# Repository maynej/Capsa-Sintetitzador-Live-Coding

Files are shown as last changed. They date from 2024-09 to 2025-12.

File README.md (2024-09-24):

# Capsa-Sintetitzador-Live-Coding
Es tracta d'una capsa per allotjar el hardware sintetitzador per realitzar Live Coding utilitzant l'entorn de Microblocks 

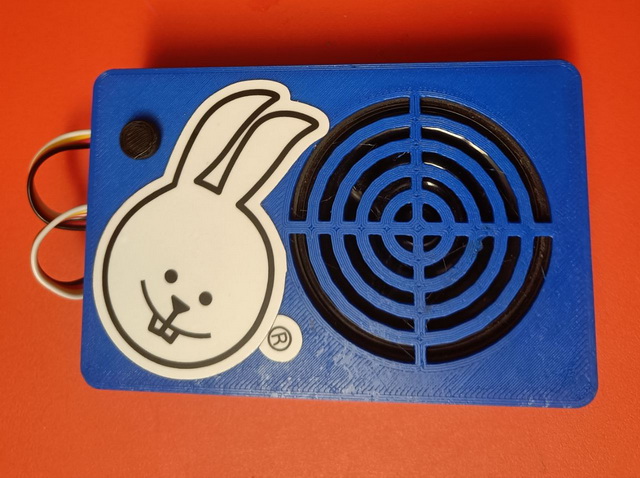
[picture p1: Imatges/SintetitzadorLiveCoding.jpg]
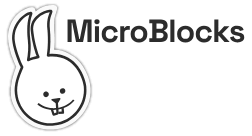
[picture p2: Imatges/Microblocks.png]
 

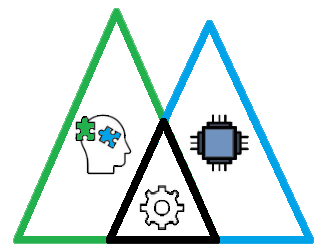
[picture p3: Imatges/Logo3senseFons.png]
Realitzat per [Jordi Mayné](https://github.com/maynej) des de Mechatronic Study jordi.mayne@mechatronicstudy.com 

La documentació està [en PDF](https://github.com/maynej/Capsa-Sintetitzador-Live-Coding/tree/main/DOC/). També amb llengua castellana.

# Arxius per imprimir 
  
Descripció         | Imatge          | Arxiu STL    
------------- | ------------- | ------------- 
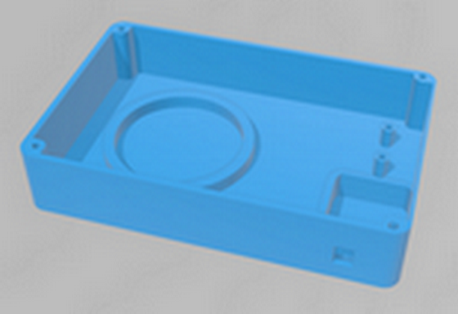
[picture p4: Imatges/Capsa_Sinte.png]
Capsa | | [Capsa](STL/Capsa_Sinte.stl)
Tapa | | [Tapa](STL/TapaPin_Sinte.stl)
Pin Polsador | | [Pin polsador](STL/Pin_Sinte.stl)
 
## Llicència
Creative Commons Attribution-NoComercial-ShareAlike 4.0 International (CC BY-NC-SA 4.0)  

## QR


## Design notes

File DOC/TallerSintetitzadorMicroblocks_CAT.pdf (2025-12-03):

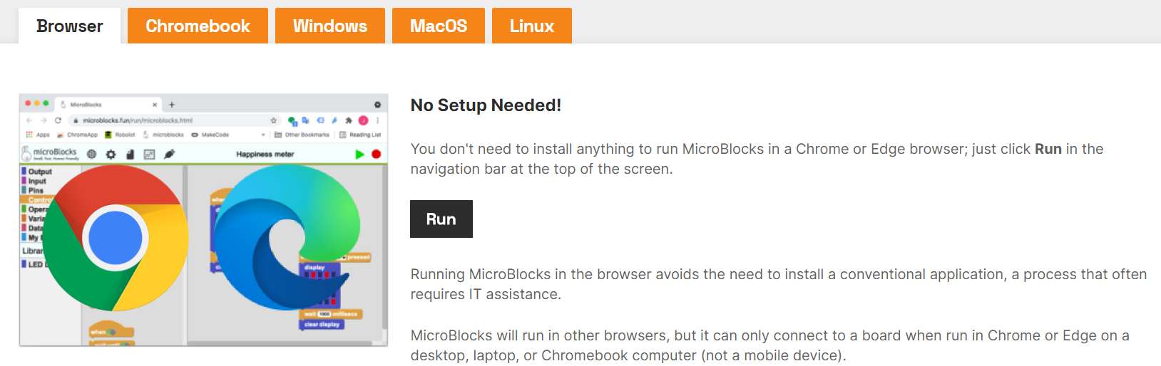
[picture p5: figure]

Jordi Mayné -2026 | 1

## Live Coding – Música programada en directe

“Fa temps que hi ha gent que programa música en directe, davant de públic. Aquesta pràctica es coneix com a «live coding» (programació en directe) i té una comunitat molt activa i apassionada arreu del món.
Normalment, els programadors de «live coding» utilitzen llenguatges que poden produir so per si mateixos, i tot i que els microcontroladors poden produir so per si mateixos, no et serà fàcil fer ballar ningú amb aquests sons.
Els microcontroladors poden interactuar amb dispositius de producció musical mitjançant un protocol anomenat MIDI. És precisament el que farem servir en aquesta activitat.” (extret de Microblocks fun)

# Taller de muntatge d’un sintetitzador

## Microblocks

MicroBlocks és un llenguatge de programació visual basat en blocs, molt basat en Snap! i semblant a d’altres amb programació amb blocs com Scratch...., que us permetrà, de manera molt fàcil i immediata, connectar-vos a diferents plaques i portar a terme projectes de computació física.

MicroBlocks té una característica que el distingeix d'altres llenguatges de programació amb blocs i és que la programació real ocorre segons es desenvolupa el programa, el que podem anomenar com a programació en directe o en viu i, a causa d'això, implica que el codi es descàrrega segons s'escriu i aquest queda gravat com a microprogramari a la placa.

Una altra de les característiques importants que ofereix MicroBlocks és la multitasca, es a dir la possibilitat de desenvolupar funcionalitats que treballen de forma paral·lela i separada, que ens serà molt útil per treballar amb un sintetitzador.

Començar amb MicroBlocks és fàcil! Només heu de seguir aquests senzills passos.

Necessitareu un ordinador (no un dispositiu mòbil!) amb un port USB, un cable USB i un hardware amb diferents possibilitats.

Podeu executar MicroBlocks en un navegador Chrome o Edge des de: https://microblocks.fun/get-started

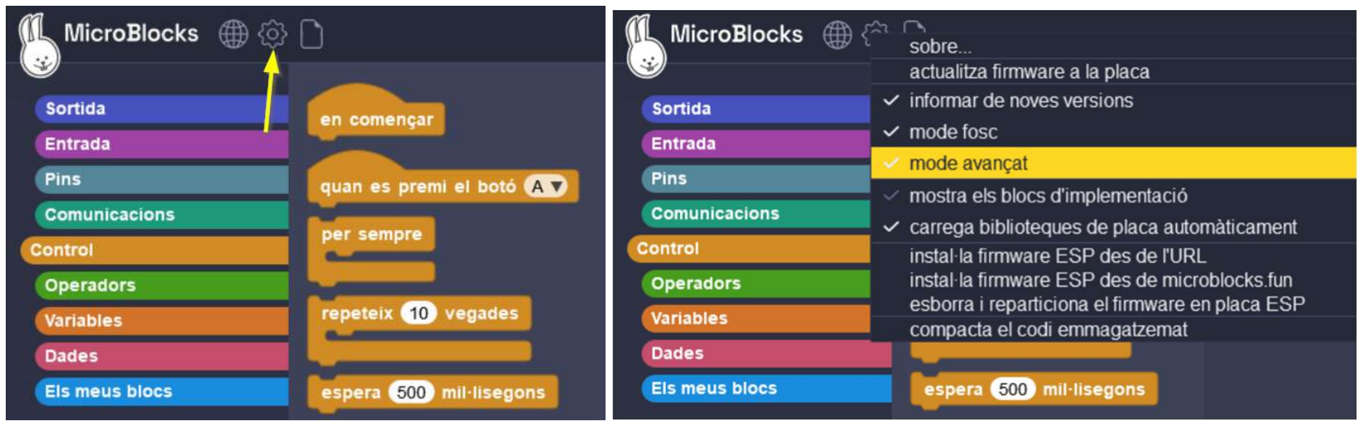
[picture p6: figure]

Jordi Mayné -2026 | 2

O descarregar una aplicació autònoma per a Chromebook, Windows, MacOS o Linux, des de Windows, per exemple, https://microblocks.fun/download. Amb la versió en línia probablement es millor per tenir actualitzades totes les seves funcions.

Al executar Microblocks ens apareixerà l’entorn de treball on podrem primer de tot seleccionar l’idioma.

Desprès cal cridar a les llibreries que farem servir per utilitzar el sintetitzador així com la placa per manegar el sintetitzador. Per el que cal clicar en símbol d’engranatge de MicroBlocks i seleccionar “mode avançat”

En aquest punt tindrem mig preparat l’entorn de programació. Més endavant es veuran els següents passos.

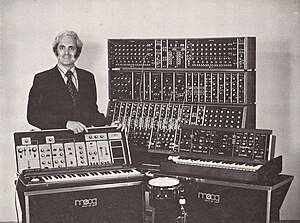
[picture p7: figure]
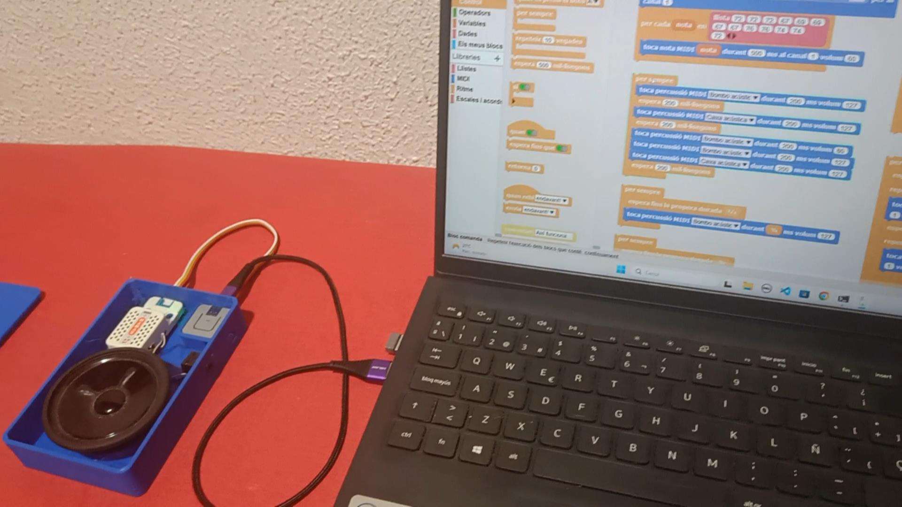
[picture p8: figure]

Jordi Mayné -2026 | 3

### Anem al Sintetitzador

El sintetitzador es un instrument musical electrònic o electròfon, que produeix so, utilitzant variacions de voltatge (en els models analògics) i amb altres tècniques com el mostreig o la modulació de freqüència (en els models digitals).

Els models analògics es van popularitzar de la ma d’en Robert Moog, un enginyer electrònic d’Estats Units en la dècada de 1960, es pot veure en la imatge la majestuositat d’alguns sintetitzadors Moog per generar sons. Que partien d’un teclat i d’una pila d’ajustos per generar freqüències, formes d’ona, harmònics, so envoltant, soroll blanc, trèmols, ... filtres, amplificadors ... d’aquí la seva complexitat, tot i això, es van popularitzar el fes-ho tu mateix, a través d’una revista americana anomenada Mecánica Popular.

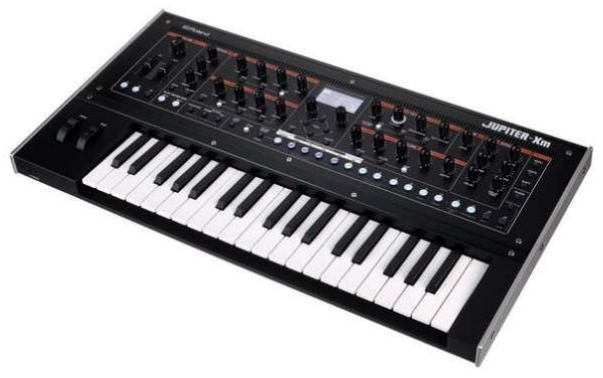
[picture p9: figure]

Avui dia amb els sintetitzadors digitals han miniaturitzat els mateixos i afegeixen moltes noves prestacions que estenen encara més el seu ús, com els “pedalers” per les guitarres elèctriques, bateries electròniques i els sintetitzadors compactes.

Per la comunicació entre sintetitzadors es fa servir un protocol estàndard MIDI (Interfície Digital d’Instruments Musicals), per el que per fer servir aquesta aplicació necessitarem un ordinador amb Microblocks, un processador que comunica entre el PC i el sintetitzador.

Jordi Mayné -2026 | 4

Informació sobre Live Coding: https://learn.microblocks.fun/ca/activities/MIDI-music-ca/

De Sintetitzadors que es poden utilitzar hi ha molts (de tot preu), però també tenim a l’abast un que en quan a preu i qualitat, dels de “fes-ho tu mateix”, els mòduls de la família M5 Stack, on fan servir el processador ESP32 i a més en diferents formats, com el mòdul Atom Matrix o Atom Lite (també s’està provant el AtomS3 Lite) que estan suportats per Microblocks.

Atom Matrix C008-B
https://docs.m5stack.com/en/core/ATOM%20Matrix

Atom Lite C008
https://docs.m5stack.com/en/core/ATOM%20Lite

AtomS3 Lite C124 (falta arranjar perquè funcioni amb el Sintetitzador) https://docs.m5stack.com/en/core/AtomS3%20Lite

Mòdul sintetitzador es el U178, que incorpora el SAM2695 de Dream, un fabricant de xips d’àudio des de 1987. A més incorpora un petit amplificador de 2,8 W i un altaveu, que permet fer un muntatge molt ràpid.
Unit Synth U178 https://docs.m5stack.com/en/unit/Unit-Synth

Es podem comprar a Mouser: https://www.mouser.es/c/?q=m5stack

Muntatge dels mòduls

El mòdul sintetitzador Unit Synth incorpora un cable d’interconnexió amb el mòdul Atom que escollim, en aquest cas Atom Lite, i aquest l’hem de connectar al nostre ordinador mitjançant un cable USB tipus C.

Ara cal instal·lar el firmware de la placa ESP que farem servir.

Anirem a https://microblocks.fun/downloads/pilot/vm/ apareixerà tota la llista i escollirem un dels mòduls Atom que tenim, ens posarem sobre del fitxer i amb el botó dret del ratolí copiarem l’enllaç.

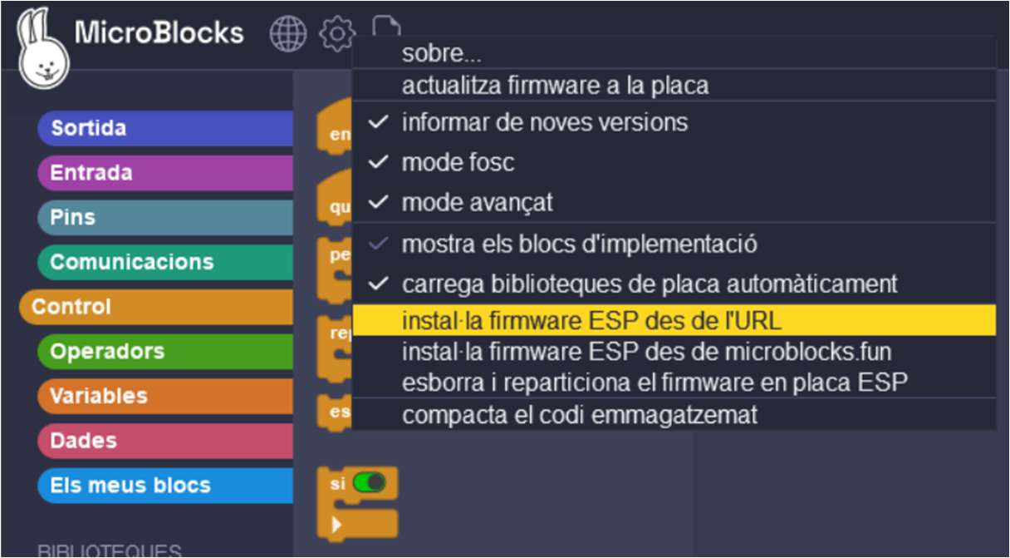
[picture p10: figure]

Jordi Mayné -2026 | 5

Tornem a Microblocks i en la rodona Microblocks seleccionem instal·lar des de la URL i enganxarem el firmware seleccionat anteriorment en la casella “firmware ESP32 des de l’URL”

Enganxarem el firmware seleccionat anteriorment i començarà a instal·lar el firmware, tarda una estona fins que arriba al 100%.

Una vegada endollat el mòdul Atom corresponent en el USB, cal anar al símbol del USB i seleccionar “connecta”

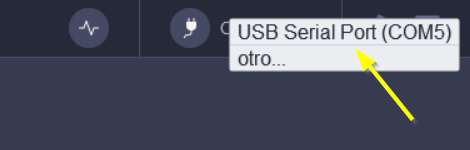
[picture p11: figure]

Ens apareixerà el port USB COM que correspongui en el nostre ordinador i connectarem, quedant el símbol del USB remarcat en color verd.

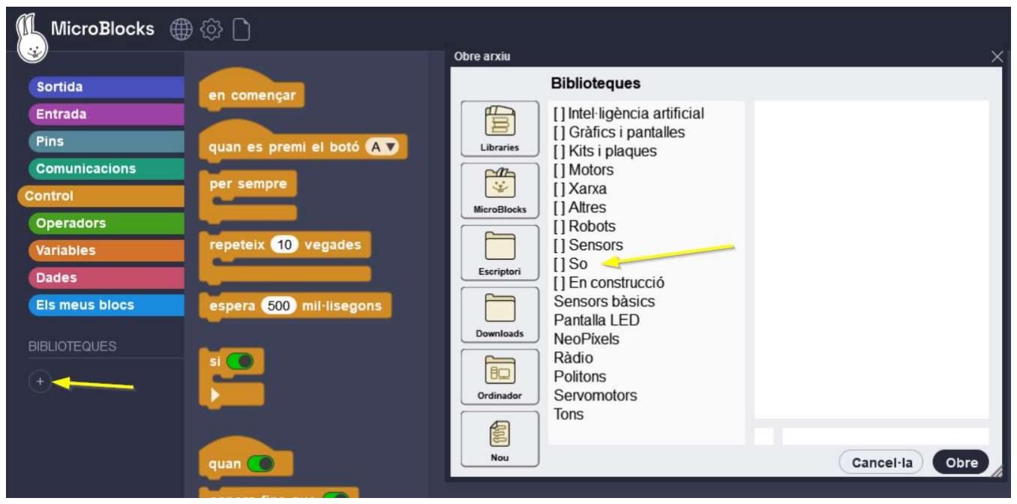
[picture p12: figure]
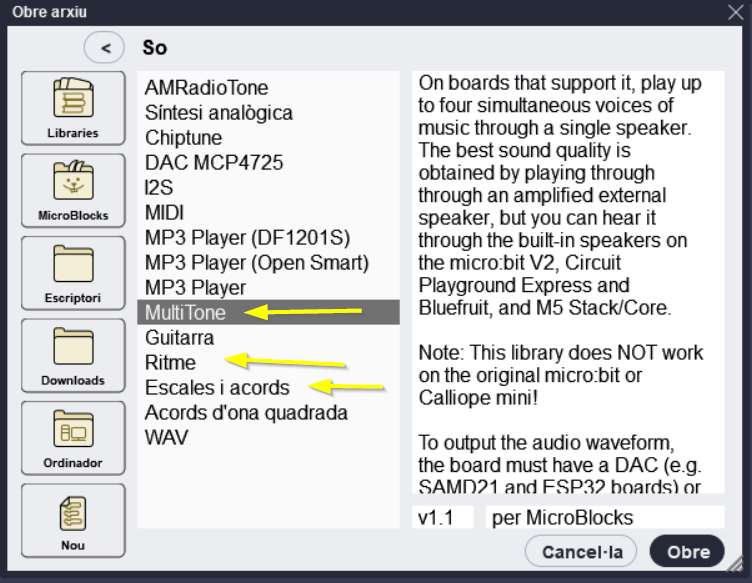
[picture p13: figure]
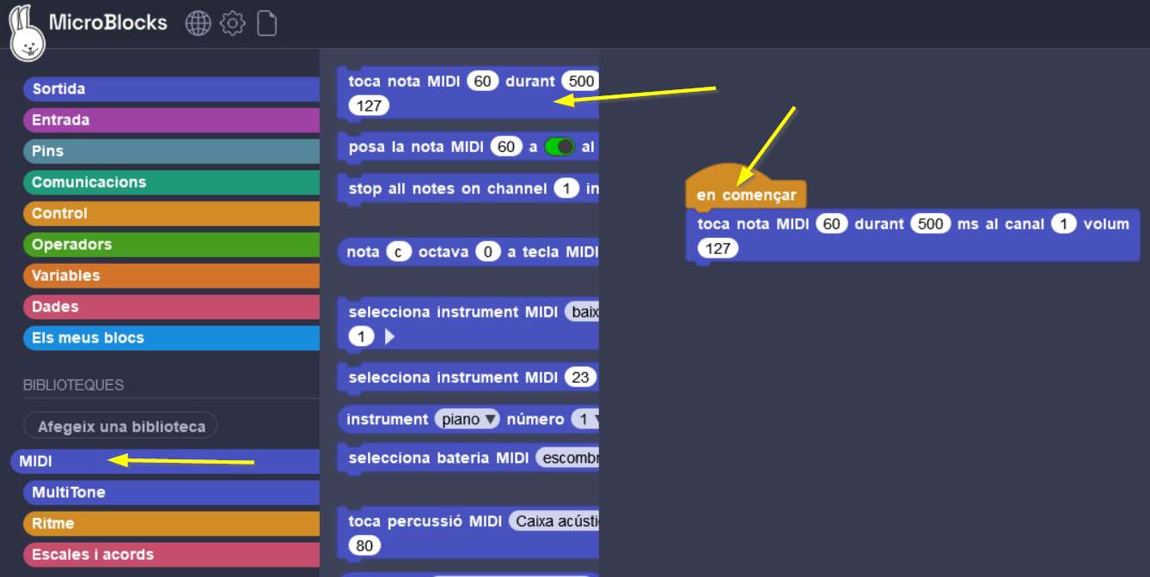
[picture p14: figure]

Jordi Mayné -2026 | 6

Ja només queda afegir les biblioteques de “So”, en la llista de l’esquerra en la part baixa seleccionem “Biblioteques”, i al obrir-se una nova finestra, seleccionarem “So”.

Dintre de “So” la llibreria principal per treballar amb el sintetitzador es MIDI, desprès es poden incloure, Multi-tone, Escales i Acords, Ritme.

Anem a provar si funciona el sintetitzador, seleccionem des de Llibreries, MIDI, i per exemple “toca nota MIDI ...”, al clicar sobre del bloc sentirem el so. Ja tenim preparat per començar a fer un programa de seqüencies.

Jordi Mayné -2026 | 7

Al protocol MIDI, cada nota musical té assignat un determinat número. Això s'entendrà millor sobre un teclat de piano:

A més, els dispositius MIDI poden reproduir música per diferents canals simultàniament. Cada canal també pot configurar-se per reproduir un instrument diferent.

Ritme: La biblioteca de Ritme, proporciona abstraccions per a durades de notes (fraccions de compassos), tempos, compassos i temps. També s'encarrega de mantenir-ho tot sincronitzat.
Aquest és l'aspecte dels blocs per a les durades:
El bloc | representa una rodona. Els altres blocs representen fraccions d'aquesta durada. Per
exemple, | representa una blanca (o la meitat d'una rodona), mentre que | representa una negra.
El tempo, expressat en PPM (pulsacions per minut o, en anglès, BPM: beats per minute), determina la velocitat de reproducció o d'interpretació de la música. A més pulsacions per minut, més ràpida és la música (perquè caben més notes en un minut).

Acords: Els acords són grups de notes que es toquen totes a la vegada. La llibreria d'Escales i acords ofereix diverses maneres de crear acords i progressions d'acords (és a dir, acords que es toquen successivament),
però en aquesta activitat només farem servir el bloc més explícit | .

Arpegis: Quan les notes que formen un acord es toquen individualment de forma successiva, en comptes de totes alhora, això s'anomena arpegi. Com que no les toquem totes de cop, en els arpegis també podem decidir l'ordre en què toquem cadascuna de les notes individuals que el formen. Diferents disposicions de notes poden generar sensacions molt diferents amb un mateix arpegi.

Aquesta informació resumida està extreta de https://learn.microblocks.fun/ca/activities/MIDI-music-ca/ on es pot ampliar els coneixements.

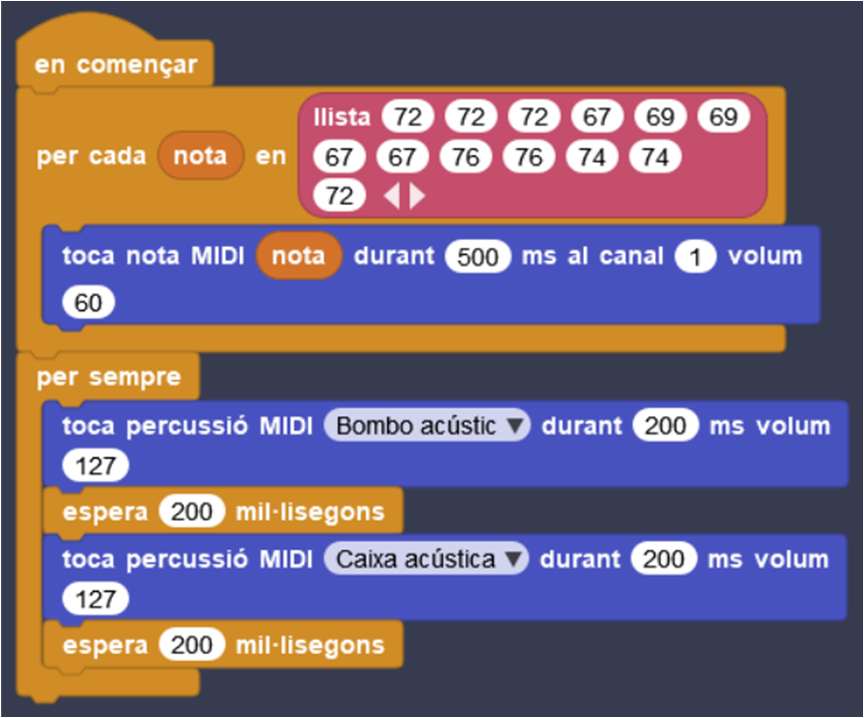
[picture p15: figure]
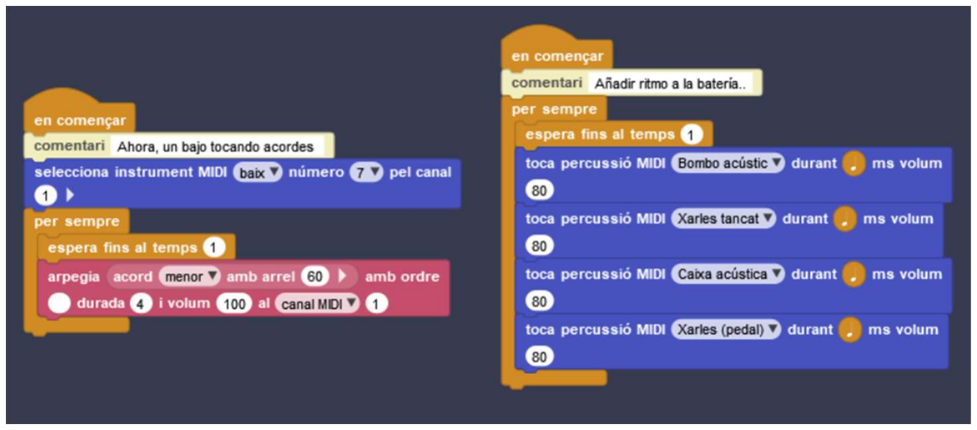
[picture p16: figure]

Jordi Mayné -2026 | 8

Alguns exemples:
Al començar toca una seqüencia de notes molt conegudes, amb una cadència de 500ms cada una i un volum de 100, després s’afegeix com percussió un Bombo acústic durant 200ms i volum 127 (valor màxim), hi ha una espera de 200ms i s’afegeix una nova percussió … i així successivament, el bucle queda tancat en la percussió.

Existeixen 128 notes MIDI i 127 velocitats de tecla possibles. La cançó comença amb 72, 72, 72… que segons la taula correspon a Do,Do,Do de la cinquena octava.

El següent exemple mostra com es selecciona un instrument, per exemple, un baix, després s’obre un llaç per sempre on un arpegi està configurat. A la vegada es pot activar el programa de la dreta amb la percussió.

Jordi Mayné -2026 | 9

### Millora de la qualitat de so del mòdul

Com es podrà entendre el mòdul sintetitzador inclou un altaveu que es molt petit i la qualitat del so, és el que és. De fet, més que un altaveu es un transductor, no pot reproduir el so requerit. Però, això la primera opció, es canviar aquest transductor per una altaveu de certa qualitat. Una altre opció es posar un jack de sortida de so i connectar-lo a un equip de música, per treure el màxim rendiment en aquest sistema. El problema es que cal un soldador de punta molt fina, una experiència en soldadura miniatura i una vista excepcional així com un pols molt acurat. Per el que no és gents recomanable.

Canviar l’altaveu del mòdul sintetitzador
Primer cal obrir el mòdul a través d’un petit cargol, per el que farem servir un clau Allen.

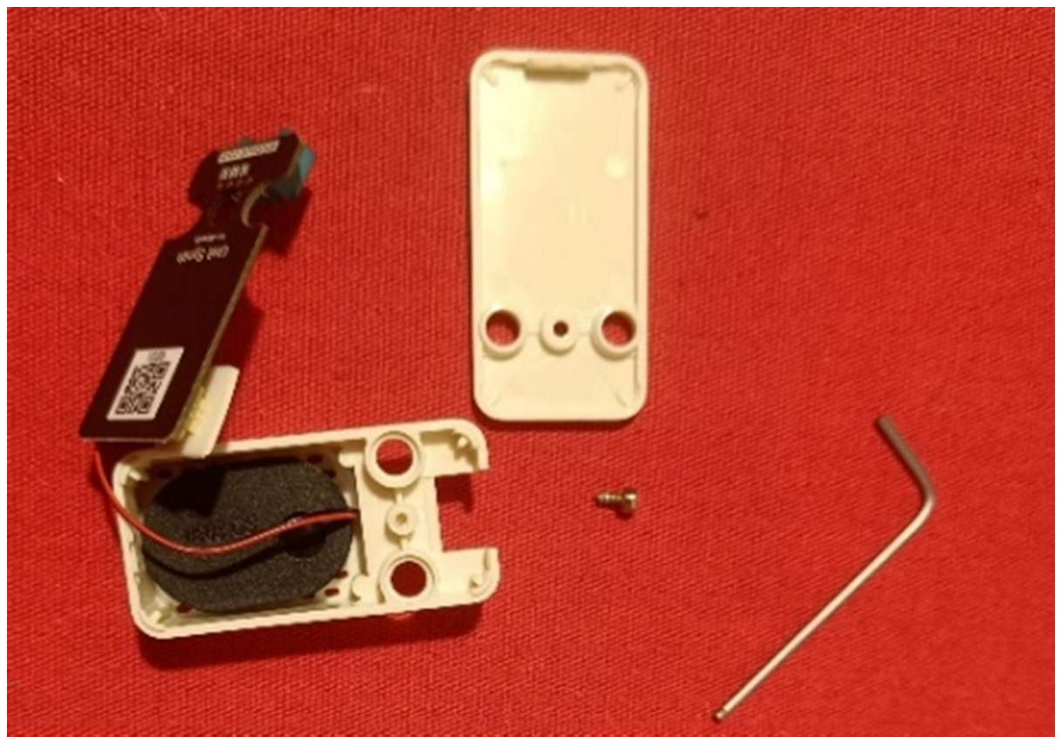
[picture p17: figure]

Amb molta cura, es separa de l’interior la placa de circuit imprès, es desconnecta el transductor (altaveu) i s’aprofita aquest connector i cable per soldar-lo en el nou altaveu de 2,7” que podem adquirir i que dona una qualitat suficient per aquesta aplicació.

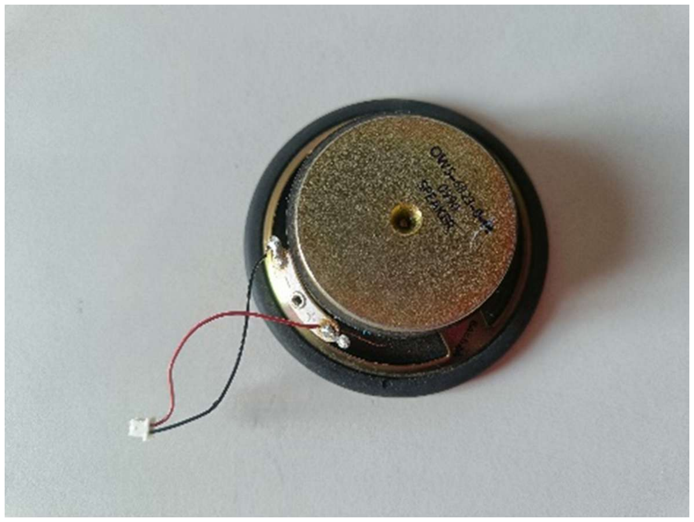
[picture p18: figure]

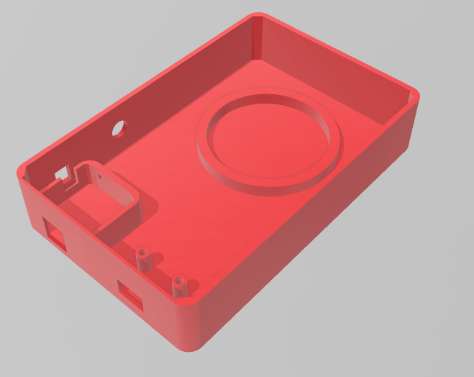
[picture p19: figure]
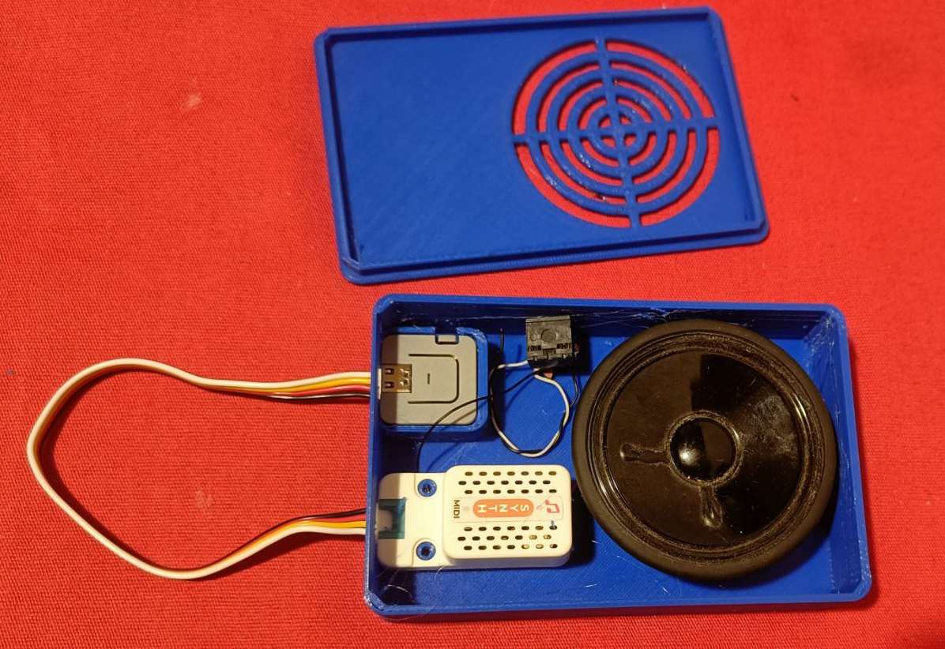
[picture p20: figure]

Jordi Mayné -2026 | 10

Capsa per posar tot el sistema

S’ha dibuixat una capsa per impressió 3D per incloure tots els components, el mòdul ATOM M5Stack, el mòdul Sintetitzador i l’altaveu.

Instal·lació dels mòduls en la capsa

Els allotjaments de la capsa permeten posar els dos mòduls i l’altaveu ràpidament.

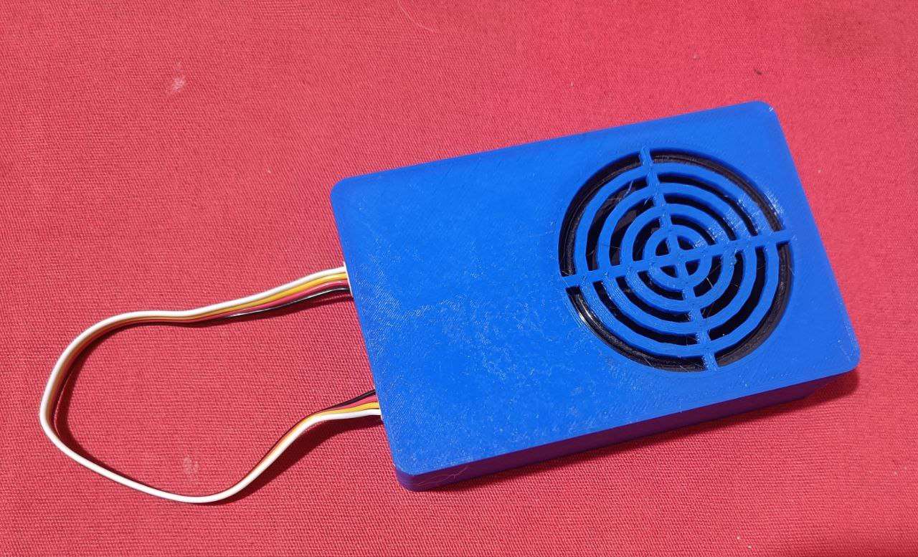
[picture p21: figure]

El cable de interconnexió entre el mòdul Atom i el Sintetitzador no es convenient que quedi fora de la capsa. Però, el mòdul Atom te el connector USB tipus C a sobre mateix del connector d’interconnexió amb el sintetitzador i no s’ha trobat un’altre solució que guardar aquest cable a través d’un forat en la propia capsa.

S’insereix el cable en aquest forat que queda simplement amagat d’intre de la capsa

Jordi Mayné -2026 | 11

### Segona solució

La solució per tenir una sortida d’àudio i fer servir un amplificador exterior passa per utilitzar el nou mòdul Sintetitzador U187 de M5 Stack. Que no inclou cap altaveu, però te entrada i sortida MIDI amb els connectors estàndards i sortida d’àudio amb jack de 3,5mm també estàndard estèreo.

U187

### Ampliant la solució i convertint-la en un “Theremin”

Un instrument que es controla amb els moviments de la ma, en aquest cas s’utilitza un sensor de distància. Sensor de distància TOF

Un sensor de distància TOF (Time Of Flight) mesura el “temps de vol” d’un pols d’infraroig làser fins un objecte reflectant i torna al sensor.
M5Stack proporciona tres models de sensors TOF, amb format Unit, el U010 fins a 2m de distància i el U172 fins a 4m de distància, amb connector I2C de 4 pins. També te disponible el U072 amb pins fins a 2m.
Tenen una millor precisió que els sensor de ultrasons i infraroigs, i no es veu alterat per les condicions ambientals com reflexos o ecos, al tenir l’angle del pols bastant estret. Les distàncies màximes de mesura son relatives al ambient, en el exterior pot reduir-la.
U172 (4m) | U010 (2m) | U072

Muntatge
La part de Atom i el sintetitzador U178 queda igual, l’ampliació és connectar el sensor TOF de distancia U172 amb un cable I2C de 4 pins fins el Atom Lite C008 (no es pot fer servir el Atom S3 Lite).
Del PC amb un cable USB connecta al USB-C del Atom LITE, del connector GROVE del Atom LITE al port del SYNTH, i del connector inferior J3 del Atom LITE al ToF4M.

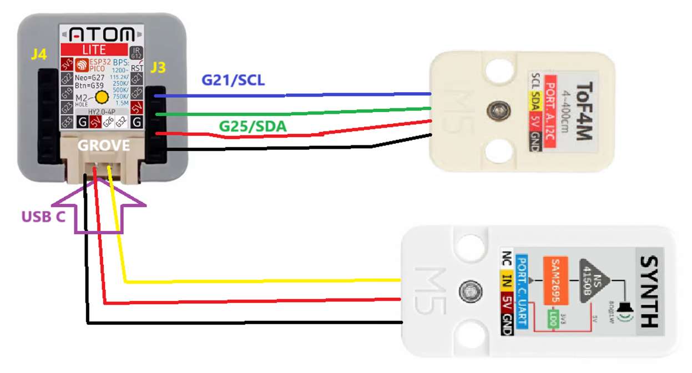
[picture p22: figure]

Jordi Mayné -2026 | 12

Ara cal programar amb Microblocks diferents rutines que podrem controlar amb la ma, de la següent manera, es divideix la distancia màxima de detecció en diferents parts, a cada part que compren dos valors actuaran a diferents rutines i obtindrem diferents composicions.

Connexió de diversos sensors ToF
El bus I2C només permet una adreça per dispositiu, de manera que us heu d'assegurar que cada dispositiu I2C tingui una adreça única. L'adreça predeterminada del VL53L1X és 0x29, però podeu canviar-ho en el programari.
Per establir la nova adreça, s’ha d'utilitzar set_address, que és fàcil de canviar, la part molesta és que els altres sensors han d'estar en shutdown. Podeu posar en shutdown cada sensor s’ha de connectar el pin XSHUT a un pin del microcontrolador.
L'exemple següent mostra com utilitzar set_address per canviar l'adreça en sensors addicionals connectats al mateix bus I2C. Estableix les adreces, imprimeix les adreces en ús i després mostra les dades de distància a la consola sèrie. Està escrit per a dos sensors, però es pot modificar fàcilment per acomodar-ne més. https://learn.adafruit.com/adafruit-vl53l1x?view=all

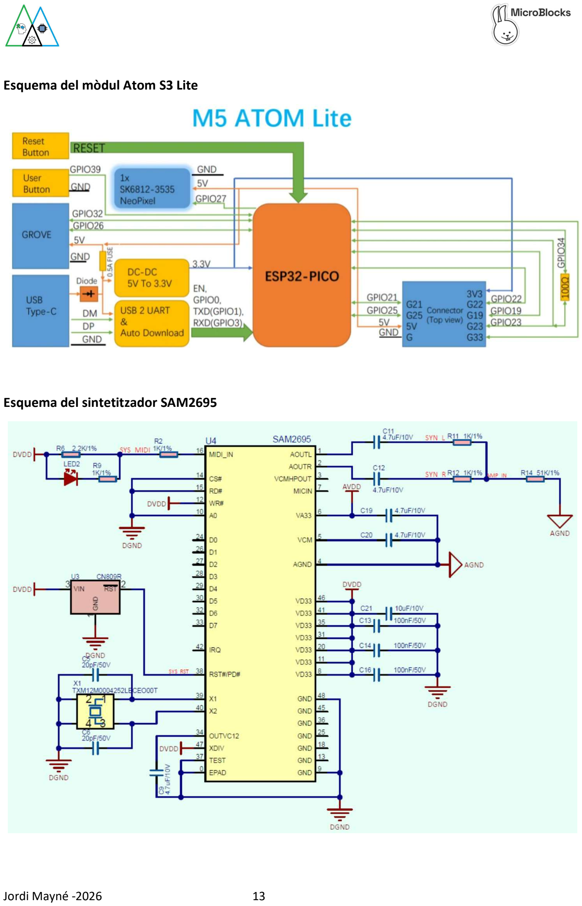
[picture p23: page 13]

Jordi Mayné -2026 | 13

Esquema del mòdul Atom S3 Lite

Esquema del sintetitzador SAM2695

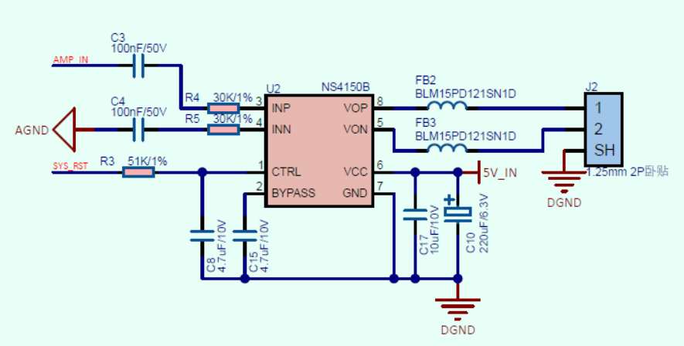
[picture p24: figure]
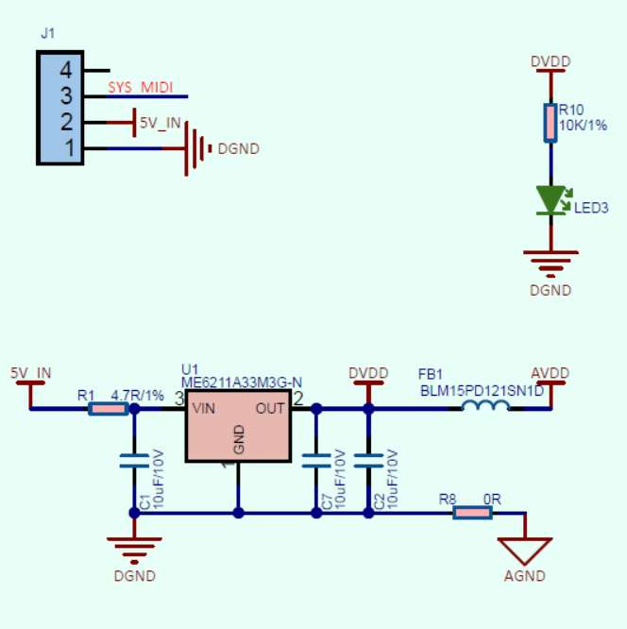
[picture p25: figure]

Jordi Mayné -2026 | 14

Esquema de l’amplificador

Esquema del connector i regulador

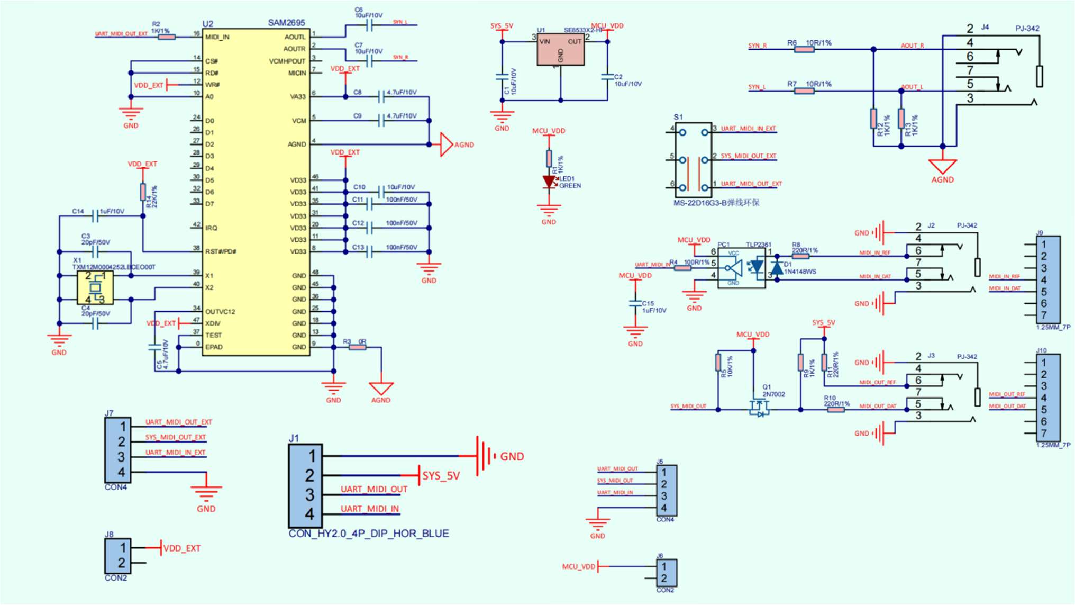
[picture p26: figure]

Jordi Mayné -2026 | 15

Mòdul Sintetitzador U187

El mòdul U187 és una unitat de control de canal i síntesi d'àudio basada en la interfície MIDI. L'interruptor de la part frontal del producte us permet configurar el mode de bypass del port MIDI esquerre/dret. En el mode Bypass, els ports esquerre i dret estan connectats directament; en el mode Separat, els ports esquerre i dret estan separats. Els ports MIDI esquerre i dret admeten interfícies estàndard DIN de 5 pins i auriculars de 3,5 mm. El pin TXD del port de cable pla està connectat al senyal del port MIDI esquerre i el pin RXD està connectat a l'entrada digital SAM2695 del sintetitzador d'àudio intern. Això permet que un host M5 extern monitoritzi o emeti senyals MIDI a través de la interfície alhora que emet àudio sintetitzat. El senyal d'àudio s'emet a través d'una presa d'auriculars de 3,5 mm. Aquest producte és adequat per a la creació i producció de música electrònica, control de música en directe i instal·lacions de música interactiva.

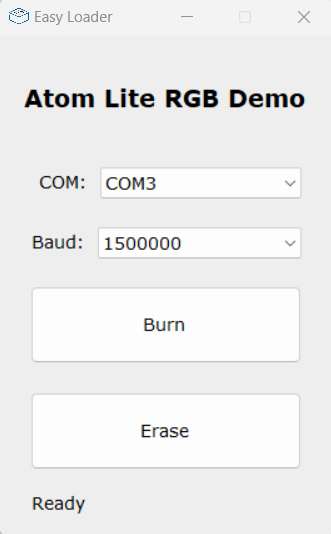
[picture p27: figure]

Jordi Mayné -2026 | 16

FAQ
En cas de quedar el mòdul Atom bloquejat i no poder transferir informació via USB, cal anar a la pàgina web de M5 Stack https://docs.m5stack.com/en/core/ATOM%20Lite i descarregar una eina Easy Loader, i executar-la. Apareixerà la següent pantalla i es seleccionarà el COM corresponent del ordinador on tinguem connectat el mòdul Atom, es selecciona Erase (esborrar) i començarà el procés fins que acabi on apareixerà Successfully

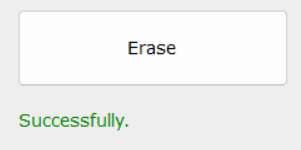
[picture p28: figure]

Desprès es pot executar Burn que és una aplicació de test que ofereix el fabricant M5 Stack. Veurem que el mòdul encén un LED de color vermell amb molta lluminositat, al polsar el botó gran que hi ha en la part superior del mòdul, canviarà a color Verd i si tornem a polsar a color Blau.

Jordi Mayné -2026 | 17

Altres solucions

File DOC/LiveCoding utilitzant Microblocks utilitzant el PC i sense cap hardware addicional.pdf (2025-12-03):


JORDI MAYNE – 2025 | 1

### LiveCoding ulitzant Microblocks amb el PC i sense cap hardware addicional

Primer descarregar el MIDI Virtual per PC, Loop MIDI hps://www.tobias-erichsen.de/soware/loopmidi.html Quan s'executa s'ha d'afegir un Port, clicant en + Add Port, apareixerà loopMIDI Port, es selecciona i quedarà així preparat.


Segon obrir l’aplicació SpessaSynth online amb el Navegador FireFox (amb Google no pot funcionar) hps://spessasus.github.io/SpessaSynth/

Si es passa el ratolí per sobra de les tecles, s’ha de senr la nota corresponent.
Per saber que Spessa està connectat a loop MIDI. Clicant a Sengs (a la dreta de la pantalla) pot aparèixer un missatge en vermell (imatge de l’esquerra), si hi ha connexió, apareix com la imatge de la dreta:



JORDI MAYNE – 2025 | 2

Tercer, ja es pot entrar a Microblocks (versió online) a hps://microblocks.fun anar a la pestanya Downloads i anar la part de baix de la pàgina i escollir Run Pilot in browser.

S’obra l’aplicació Microblocks i es pot escollir l’idioma desitjat.


Desprès cal afegir Biblioteques, com MIDI, Ritmes, Escales i Acords, i quedaran preparades per ulitzar.


Ara es connecta Microblocks a l’aplicació Spessa, seleccionant Open Boardie.

Apareixerà una finestreta Boardie. Per provar que funciona, s’agafa, per exemple Si cliquem sobra d’aquest bloc, senrem aquesta nota a través dels altaveus del ordinador.


JORDI MAYNE – 2025 | 3

Seguidament es podrà confeccionar un programa ulitzant els blocs de les biblioteques de MIDI, Ritme, Escales i Acords.


JORDI MAYNE – 2025 | 4

Ritmes i Improvisació

Coses a provar:

Transportar octaves, sumar o treure 12 a l’arrel

Canviar els compassos

Jugar amb les durades del improvisador


JORDI MAYNE – 2025 | 5

### Musica ambiental

Ara pots jugar amb el compàs, el tempo, les notes, les durades, el volums ...

### i gaudir creant musica en viu

### Agraïments a Bernat Romagosa per la musica mostrada

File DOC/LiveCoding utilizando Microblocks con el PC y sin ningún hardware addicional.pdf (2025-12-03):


JORDI MAYNE – 2025 | 1

### LiveCoding ulizando Microblocks con el PC y sin ningún hardware adicional

Primero descargar el MIDI Virtual para PC, Loop MIDI hps://www.tobias-erichsen.de/soware/loopmidi.html Cuando se ejecuta se debe añadir un Puerto, clicando en + Add Port, aparecerá loopMIDI Port, se selecciona. Así quedará preparado.


Segundo abrir con el Navegador FireFox (con Google puede que no funcione) la aplicación online SpessaSynth hps://spessasus.github.io/SpessaSynth/

Si se pasa el ratón por encima de las teclas se oye la nota correspondiente.
Para saber que Spessa está conectado a loop MIDI. Clicando en Sengs en la derecha de la pantalla, puede aparecer el mensaje en rojo (imagen de la izquierda), si hay conexión, aparece como la imagen de la derecha:



JORDI MAYNE – 2025 | 2

Tercero, ya se puede entrar en Microblocks (versión online) hps://microblocks.fun, ir a la pestaña Downloads y en la parte baja de lapágina escoger Run Pilot in browser. Nota: por ahora y hasta que sea estable esta aplicación de MIDI no estará en versión offline.

Se abre la aplicación Microblocks, se puede escoger el idioma


Ahora hace falta añadir las librerías de sonido, como MIDI, Ritmos, Escalas y Acordes, así quedaran preparadas para ulizar.


Ara se conecta Microblocks, a la aplicación Spessa selecionando Open Boardie

Aparece la ventanita Boardie. Para probar que funciona, se escoge, por ejemplo, . Si se clica encima de este bloque, ya se oirá la nota a través de los altavoces del ordenador.


JORDI MAYNE – 2025 | 3

Seguidamente se podrá confeccionar un programa ulizando los bloques de las librerías de MIDI, Ritmo, Escalas y Acordes.


JORDI MAYNE – 2025 | 4

Ritmos e Improvisación

Cosas a probar:

Transporta octavas, suma o resta 12 en la raíz

Cambia los compases

Juega con las duraciones del improvisador


JORDI MAYNE – 2025 | 5

### Música ambiental

### Ahora puedes jugar con el compás, el tempo, las notas, las duraciones, el volumen… y a disfrutar creando música en vivo

### Agradecimientos a Bernat Romagosa per la música mostrada

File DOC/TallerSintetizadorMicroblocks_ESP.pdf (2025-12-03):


Jordi Mayné -2026 | 1

## Live Coding – Música programada en directo

“Hace tiempo que hay gente programa música en directo frente al público. Esta práctica se conoce como “live coding” (programación en directo) y tiene una comunidad muy activa y apasionada en todo el mundo.
Normalmente, los programadores de “live coding” utilizan lenguajes que pueden producir sonido por sí mismos, y aunque los microcontroladores pueden producir sonido por sí mismos, no te será fácil hacer bailar a nadie con estos sonidos.
Los microcontroladores pueden interactuar con dispositivos de producción musical mediante un protocolo llamado MIDI. Es precisamente lo que vamos a utilizar en esta actividad.” (extraído de Microblocks)

# Taller de montaje de un sintetizador

## Microblocks

MicroBlocks es un lenguaje de programación visual basado en bloques, basado en Snap! y similar a otros con programación con bloques como Scratch..., que le permitirá, de manera muy fácil e inmediata, conectarse a diferentes placas y llevar a cabo proyectos de computación física.

MicroBlocks tiene una característica que le distingue de otros lenguajes de programación con bloques y es que la programación real ocurre según se desarrolla el programa, lo que podemos llamar como programación en directo o en vivo y debido a ello, implica que el código se descarga según se escribe y éste queda grabado como firmware en la placa.

Otra de las características importantes que ofrece MicroBlocks es la multitarea, es decir, la posibilidad de desarrollar funcionalidades que trabajan de forma paralela y separada, que nos será muy útil para trabajar con un sintetizador.

¡Empezar con MicroBlocks es fácil! Sólo tiene que seguir estos sencillos pasos.

Necesitará un ordenador (¡no un dispositivo móvil!) con un puerto USB, un cable USB y un hardware con diferentes posibilidades.

Puede ejecutar MicroBlocks en un navegador Chrome o Edge desde: https://microblocks.fun/get-started

Jordi Mayné -2026 | 2

O descargar una aplicación autónoma para Chromebook, Windows, MacOS o Linux, desde por ejemplo, para
Windows https://microblocks.fun/download. Con la versión online probablemente es mejor por tener actualizadas todas sus funciones o la versión Pilot.

Al ejecutar Microblocks nos aparecerá el entorno de trabajo, donde podremos primero seleccionar el idioma.


Después es necesario llamar a las librerías que utilizaremos para utilizar el sintetizador, así como la placa que utilizaremos para manejar el sintetizador. Por lo que hace falta hacer un clic en el símbolo de engranaje de MicroBlocks y seleccionar “modo avanzado”


En este punto tendremos medio preparado el entorno de programación. Más adelante se verán los siguientes pasos.


Jordi Mayné -2026 | 3

### Vayamos al Sintetizador

El sintetizador es un instrumento musical electrónico o electrófono, que produce sonido utilizando variaciones de voltaje (en los modelos analógicos) y con otras técnicas como el muestreo o la modulación de frecuencia (en los modelos digitales).

Los modelos analógicos se popularizaron de la mano de Robert Moog, un ingeniero electrónico de Estados Unidos en la década de 1960, se puede ver en la imagen la majestuosidad de algunos sintetizadores Moog para generar sonidos. Que partían de un teclado y de un montón de ajustes para generar frecuencias, formas de onda, armónicos, envolvente, ruido blanco, tremoles, ... filtros, amplificadores ... de ahí su complejidad, sin embargo se popularizaron al hazlo tú mismo, a través de una revista americana llamada Mecánica Popular.

Hoy en día con los sintetizadores digitales han miniaturizado los mismos y añaden muchas nuevas prestaciones y se ha extendido aún más su uso, como en pedaleras por las guitarras eléctricas, baterías electrónicas y los sintetizadores compactos.

Para la comunicación entre sintetizadores se utiliza un protocolo estándar MIDI (Interfaz Digital de Instrumentos Musicales), por lo que para utilizar esta aplicación necesitaremos un ordenador con Microblocks, un procesador que comunica entre el PC y el sintetizador.

Jordi Mayné -2026 | 4

Información sobre Live Coding: https://learn.microblocks.fun/ca/activities/MIDI-music-ca/

De Sintetizadores hay muchos y precios diversos que se podrían utilizar, pero también tenemos al alcance uno que en cuanto a precio y calidad de los de “hazlo tú mismo”, son los módulos de la familia M5 Stack, que utilizan el procesador ESP32 y además en diferentes formatos como el módulo Atom Matrix o Atom Lite (también se está probando el AtomS3 Lite) que están soportados por Microblocks.

Atom Matrix
https://docs.m5stack.com/en/core/ATOM%20Matrix

Atom Lite U178
https://docs.m5stack.com/en/core/ATOM%20Lite

AtomS3 Lite
https://docs.m5stack.com/en/core/AtomS3%20Lite

Modulo sintetizador es el U178, que incorpora el SAM2695 de Dream, un fabricante de chips de audio desde 1987. Además, incorpora un pequeño amplificador de 2,8 W y un altavoz, que permite hacer un montaje muy rápido.
Unit Synth U178 https://docs.m5stack.com/en/unit/Unit-Synth

Se pueden comprar en Mouser: https://www.mouser.es/c/?q=m5stack

Montaje de los módulos

El módulo sintetizador Unit Synth incorpora un cable de inter-conexionado con el módulo Atom que hemos escogido, en este caso el Atom Lite, y este lo hemos de conectar a nuestro ordenador mediante un cable USB tipo C.

Ahora hace falta instalar el firmware de la placa ESP que utilizaremos.

Iremos a https://microblocks.fun/downloads/pilot/vm/ aparecerá toda la lista y escogeremos uno de los módulos Atom que tenemos, nos pondremos sobre del fichero y con el botón derecho del ratón copiaremos el enlace.


Jordi Mayné -2026 | 5

Volvemos a Microblocks y en el símbolo engranaje, seleccionamos instalar firmware desde una URL y pegaremos el firmware seleccionado anteriormente en la casilla “firmware ESP32 desde la URL”


Pegaremos el firmware seleccionado anteriormente (copiar dirección de enlace) y empezará a instalar el firmware, tarda un rato hasta que llega al 100%.

Al final desconectar el módulo Atom del puerto USB y volver a conectar, siendo necesario ir al símbolo del USB y seleccionar “conecta”

Nos aparecerá el puerto USB COM que corresponda a nuestro ordenador y conectaremos, quedando el símbolo del USB remarcado en color verde.


Jordi Mayné -2026 | 6

Ya sólo queda añadir las bibliotecas de sonido, en la lista de la izquierda en la parte baja seleccionamos “Bibliotecas”, y al abrirse una nueva ventana, seleccionaremos “Sonido”.

Dentro de “Sonido”, la librería principal para trabajar con el sintetizador es MIDI, después se pueden añadir Multitone, Escalas y Acordes, Ritmo.

Vamos a probar si funciona el sintetizador, seleccionamos desde Librerías, MIDI, y por ejemplo “toca nota MIDI...”, al pulsar sobre el bloque oiremos el sonido. Ya tenemos preparado para empezar a programar secuencias.


Jordi Mayné -2026 | 7

Algunos ejemplos:
Al empezar toca una secuencia de notas muy conocidas, con una cadencia de 500ms cada una y un volumen de 100, después se añade como percusión un Bombo acústico durante 200ms y volumen 127 (valor máximo), hay una espera de 200ms y se añade otra percusión … y así sucesivamente, el bucle queda cerrado en la percusión.

Existen 128 notas MIDI y 127 velocidades de tecla posibles. En la canción empieza con 72, 72, 72… que según la tabla corresponde a Do,Do,Do de la quinta octava.

El siguiente ejemplo muestra como se selecciona un instrumento, por ejemplo, un bajo, después se abre un bucle para siempre donde un arpegio está configurado. A la vez se puede activar el programa de la derecha con la percusión.


Jordi Mayné -2026 | 8

### Mejora de la calidad de sonido del módulo

Cómo se podrá entender el módulo sintetizador incluye un altavoz que es muy pequeño y la calidad del sonido es lo que es. De hecho, más que un altavoz es un transductor, no puede reproducir el sonido requerido. Sin embargo, la primera opción, es cambiar este transductor por un altavoz de cierta calidad. Otra opción es poner un jack de salida de sonido y conectarlo a un equipo de música, para sacar el máximo rendimiento a este sistema. El problema es que es necesario un soldador de punta muy fina, una experiencia en soldadura miniatura y una vista excepcional, así como un pulso muy cuidado. Por lo que no es nada recomendable.

Cambiar el altavoz del módulo sintetizador
Primero hay que abrir el módulo a través de un pequeño tornillo, por lo que utilizaremos una llave Allen.


Con mucho cuidado, se separa del interior la placa de circuito impreso, se desconecta el transductor (altavoz) y se aprovecha este conector y cable para soldarlo en el nuevo altavoz de 2,7” que podemos adquirir y que da una calidad suficiente para esta aplicación.



Jordi Mayné -2026 | 9

Caja para poner todo el sistema

Se ha dibujado una caja para ser impresa en 3D para incluir todos los componentes; el módulo ATOM M5Stack, el módulo Sintetizador y el altavoz.

Instalación de los módulos en la caja


Los alojamientos de la caja permiten poner los dos módulos y el altavoz rápidamente.


El cable de interconexión entre el módulo Atom y el Sintetizador no es conveniente que quede fuera de la caja. Sin embargo, el módulo Atom tiene el conector USB tipo C encima mismo del conector de interconexión con el sintetizador y no se ha encontrado otra solución que guardar este cable a través de un agujero en la propia caja.

Se inserta el cable en ese agujero que queda simplemente escondido dentro de la caja.



Jordi Mayné -2026 | 10

### Segunda solución

La solución para tener una salida de audio y utilizar un amplificador externo, pasa por utilizar el nuevo módulo Sintetizador U187 de M5 Stack. Que no incluye ningún altavoz, pero tiene entrada y salida MIDI con los conectores estándar y salida de audio con jack de 3,5mm también estándar estéreo.


Jordi Mayné -2026 | 11

Esquema del módulo Atom S3 Lite

Esquema del sintetizador SAM2695


Jordi Mayné -2026 | 12

Esquema del amplificador

Esquema del conector y regulador


Jordi Mayné -2026 | 13

Módulo Sintetizador U187

El módulo U187 es una unidad de control de canal y síntesis de audio basada en la interfaz MIDI. El interruptor de la parte frontal del producto le permite configurar el modo de bypass del puerto MIDI izquierdo/derecho. En modo Bypass, los puertos izquierdo y derecho están conectados directamente; en modo Separado, los puertos izquierdo y derecho están separados. Los puertos MIDI izquierdo y derecho admiten interfaces estándar DIN de 5 pines y auriculares de 3,5 mm. El pin TXD del puerto de cable plano está conectado a la señal del puerto MIDI izquierdo y el pin RXD está conectado a la entrada digital SAM2695 del sintetizador de audio interno. Esto permite que un host M5 externo monitorice o emita señales MIDI a través de la interfaz a la vez que emite audio sintetizado. La señal de audio se emite a través de una toma de auriculares de 3,5 mm. Este producto es adecuado para la creación y producción de música electrónica, control de música en directo e instalaciones de música interactiva.

Jordi Mayné -2026 | 14

FAQ
En caso de quedar el módulo Atom bloqueado y no poder transferir información vía USB, es necesario ir a la página web de M5 Stack https://docs.m5stack.com/en/core/ATOM%20Lite y descargar una herramienta Easy Loader, ejecutarla. Aparece la siguiente pantalla y se selecciona el COM correspondiente del ordenador al que tengamos conectado el módulo Atom, se selecciona Erase (borrar) y empezará el proceso hasta que acabe donde aparecerá Successfully


Después se puede ejecutar Burn que es una aplicación de test que ofrece el fabricante M5 Stack. Veremos que el módulo enciende un LED de color rojo con mucha luminosidad, al pulsar el botón grande que hay en la parte superior del módulo, cambiará a color Verde y si volvemos a pulsar a color Azul.

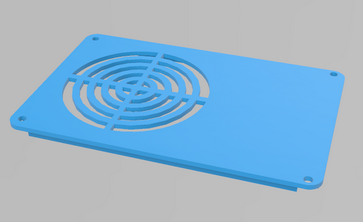
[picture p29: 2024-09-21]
Imatges/Tapa_Sinte.png

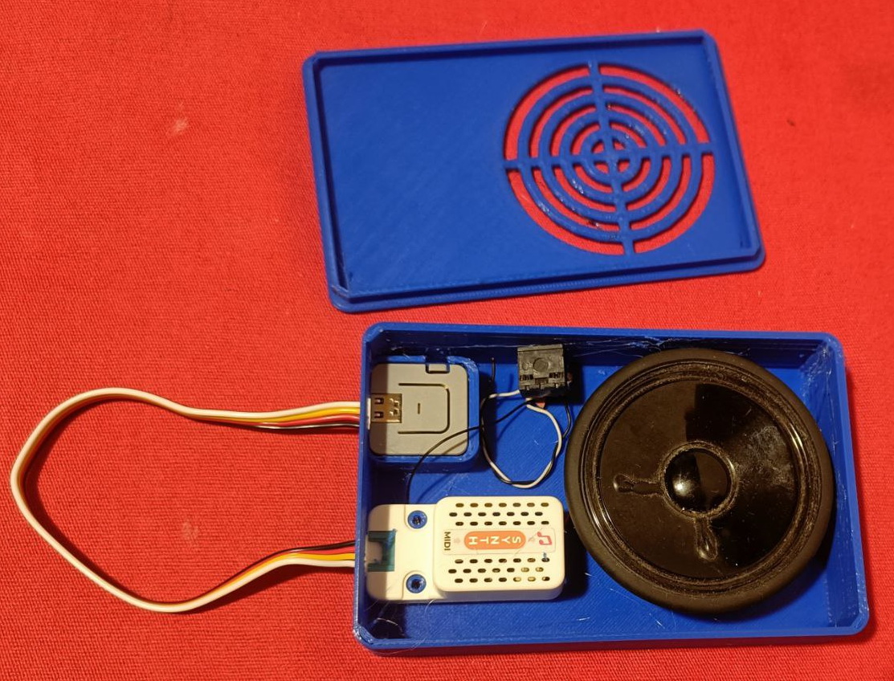
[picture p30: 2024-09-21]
Imatges/SintetitzadorObert.jpg

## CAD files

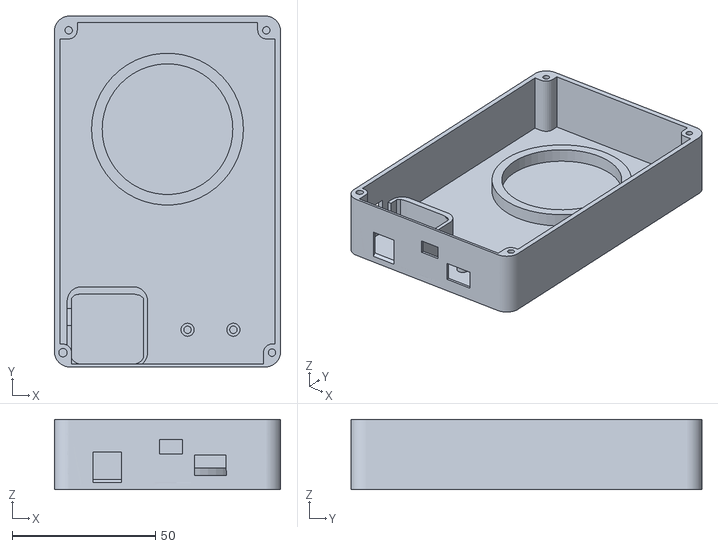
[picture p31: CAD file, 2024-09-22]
STL/Capsa_Sinte.stl
79.0 x 122.5 x 24.5

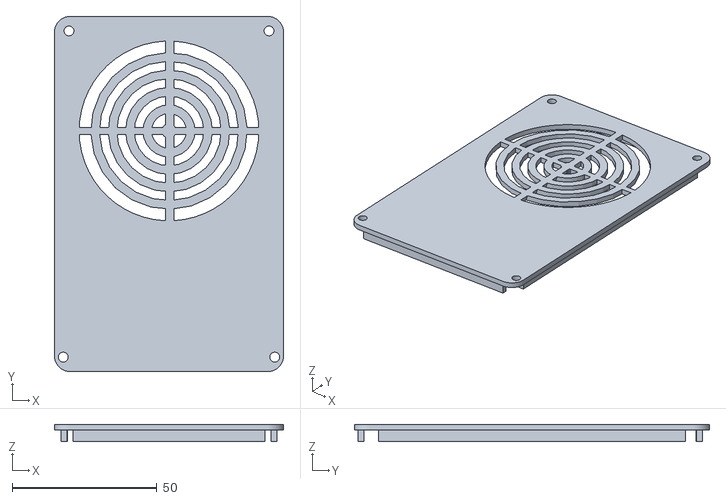
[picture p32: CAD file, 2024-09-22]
STL/Tapa_Sinte.stl
79.0 x 122.5 x 6.00

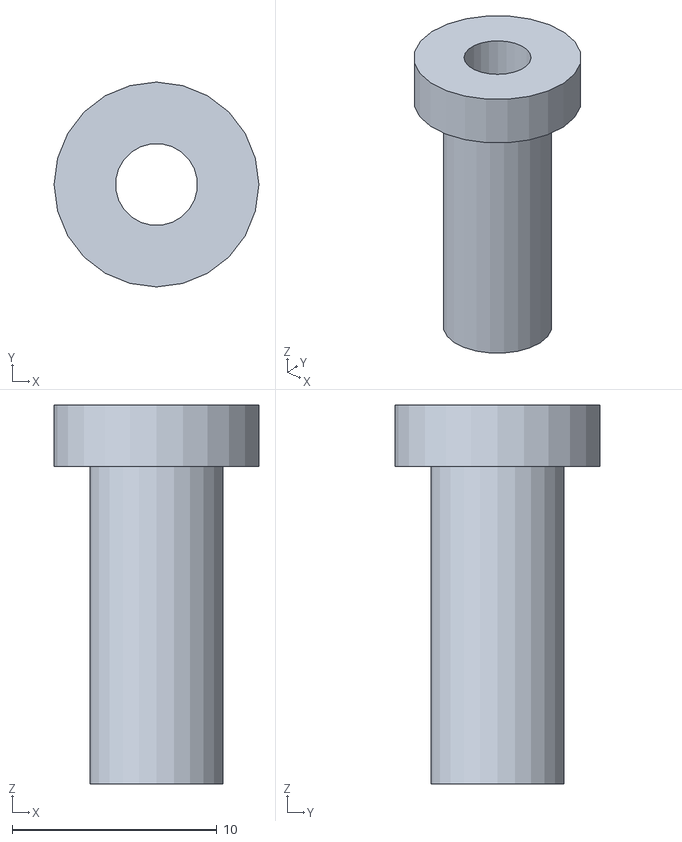
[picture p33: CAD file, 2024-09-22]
STL/Pin_Sinte.stl
10.00 x 10.00 x 18.5

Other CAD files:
STL/TapaPin_Sinte.stl
STL/Capsa_Sinte_Audio.stl
